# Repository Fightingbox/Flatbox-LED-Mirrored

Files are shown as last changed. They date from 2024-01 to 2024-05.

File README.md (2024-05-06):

# Flatbox-LED-Mirrored
Based on the [GP2040-CE](https://github.com/OpenStickCommunity/GP2040-CE) Flatbox Rev4

Add the colorful LEDs and the OLED display, perfect hardware change beased on the [Flatbox](https://github.com/jfedor2/flatbox) design by [jfedor2](https://github.com/jfedor2) powered by an RP2040 MCU.

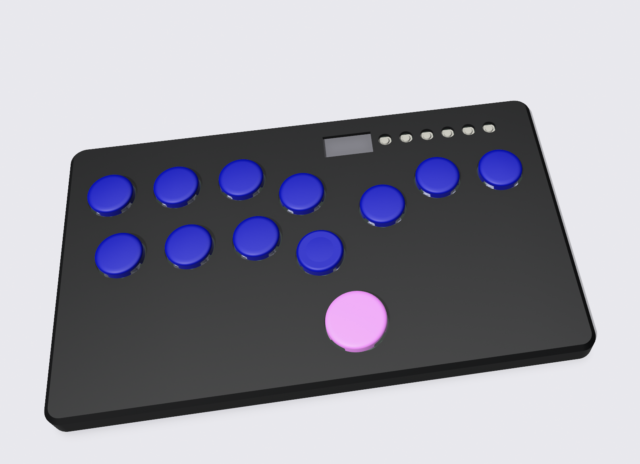
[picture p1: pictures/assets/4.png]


Flatbox-LED

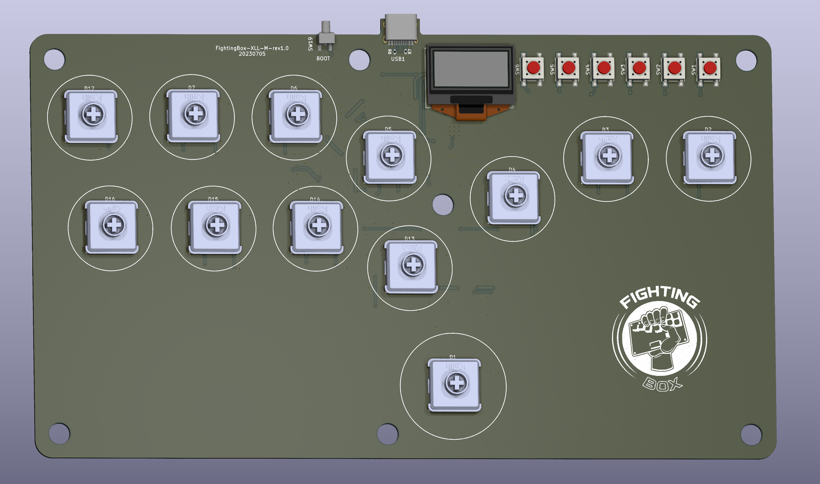
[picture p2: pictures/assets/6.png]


## Upgrade the firmware:
- Unplug your device.
- Put your device into Bootsel/USB mode. A new removable drive named RPI-RP2 should appear in your file explorer.
- Drag and drop the GP2040-CE_XXX.uf2 firmware into the removable drive.
- Wait for the device to automatically disconnect.

### If you encounter problems updating firmware, please refer to the official firmware update [Tutorial](https://gp2040-ce.info/?spm=a2g0o.detail.1000023.2.163cu936u936KZ#/installation).

## GP2040-CE Links

[Downloads](https://gp2040-ce.info/#/download) | [Installation](https://gp2040-ce.info/#/installation) | [Wiring](https://gp2040-ce.info/#/wiring) | [Usage](https://gp2040-ce.info/#/usage) | [FAQ](https://gp2040-ce.info/#/faq) | [GitHub](https://github.com/OpenStickCommunity/GP2040-CE)

Full documentation can be found at <https://gp2040-ce.info>

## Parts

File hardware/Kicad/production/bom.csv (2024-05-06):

Designator | Footprint | Quantity | Value | LCSC Part #
C1, C10, C4, C8 | 0402 | 4 | 1u | C52923
C11, C12, C13, C14, C15, C16, C5, C6, C7, C9 | 0402 | 10 | 100n | C1525
C17, C19 | 0402 | 2 | 1uF
C18 | 0603 | 1 | 4.7uF
C2, C3 | 0402 | 2 | 5p | C1570
C20 | 0603 | 1 | 2.2uF
D1, D12, D13, D14, D15, D16, D2, D3, D4, D5, D6, D7 | Kailh_socket_PG1353_LED_1U-4.8MM | 12 | KB_HOTSWAP_WS2812B
DS1 | TE_CON-0_1x30-1MP_P0.5mm_Horizontal-OLED-FPC | 1 | OLED-128O064D
H1, H2, H3, H4, H5, H6, H7 | MountingHole_6mm | 7 | MountingHole
R1, R5 | 0402 | 2 | 1k | C11702
R15 | 0402 | 1 | 390K
R16, R17 | 0402 | 2 | 4.7K
R2 | 0402 | 1 | 10k | C25744
R3, R4 | 0402 | 2 | 27 | C138021
R6, R7 | 0402 | 2 | 5.1k | C25905
SW1, SW2, SW3, SW4, SW5, SW6 | SW_Push_1P1T_NO_6x6mm_H5mm | 6 | SW_Push
SW19 | SW-K2-1109SE | 1 | SW_Push | C271750
U1 | SOT-23-5 | 1 | TLV73333PDBV | C134139
U2 | SOIC-8_5.23x5.23mm_P1.27mm | 1 | W25Q128JVS | C97521
U3 | RP2040-QFN-56 | 1 | RP2040 | C2040
USB1 | HRO-TYPE-C-31-M-12-Assembly | 1 | HRO-TYPE-C-31-M-12 | C165948
Y1 | Crystal_SMD_3225-4Pin_3.2x2.5mm | 1 | Crystal_GND24 | C9002

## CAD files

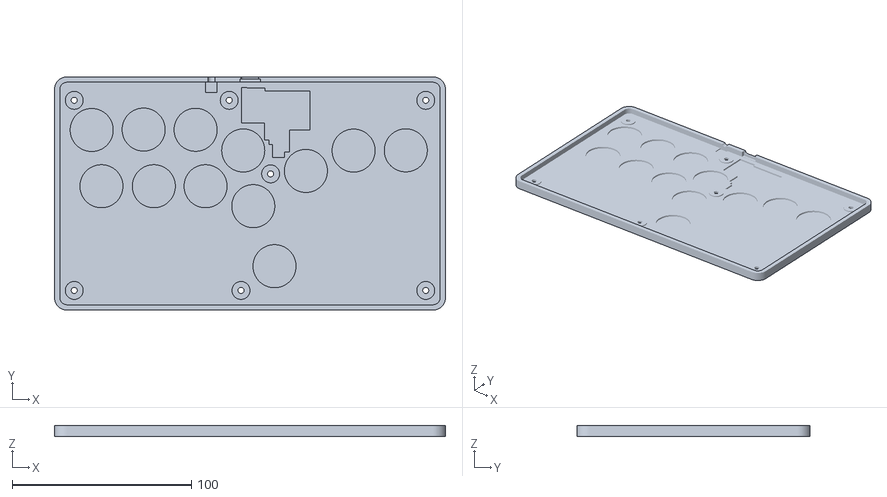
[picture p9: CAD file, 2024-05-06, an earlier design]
case/FightingBox-XLL-Mirror-Bottom-0711.stl
218.0 x 130.1 x 6.00

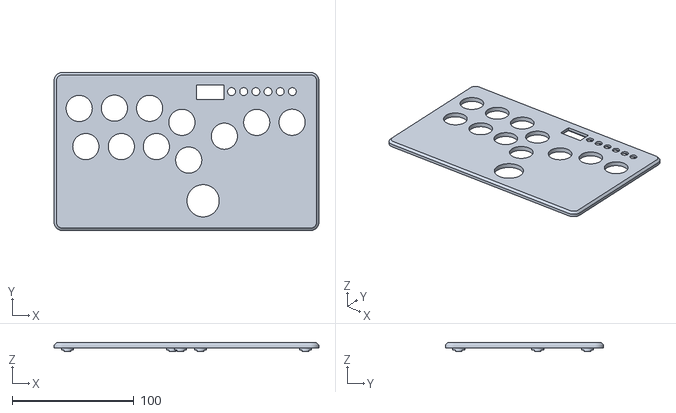
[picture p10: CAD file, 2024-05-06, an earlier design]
case/FightingBox-XLL-Mirror-TOP-0706.stl
218.0 x 130.1 x 7.20

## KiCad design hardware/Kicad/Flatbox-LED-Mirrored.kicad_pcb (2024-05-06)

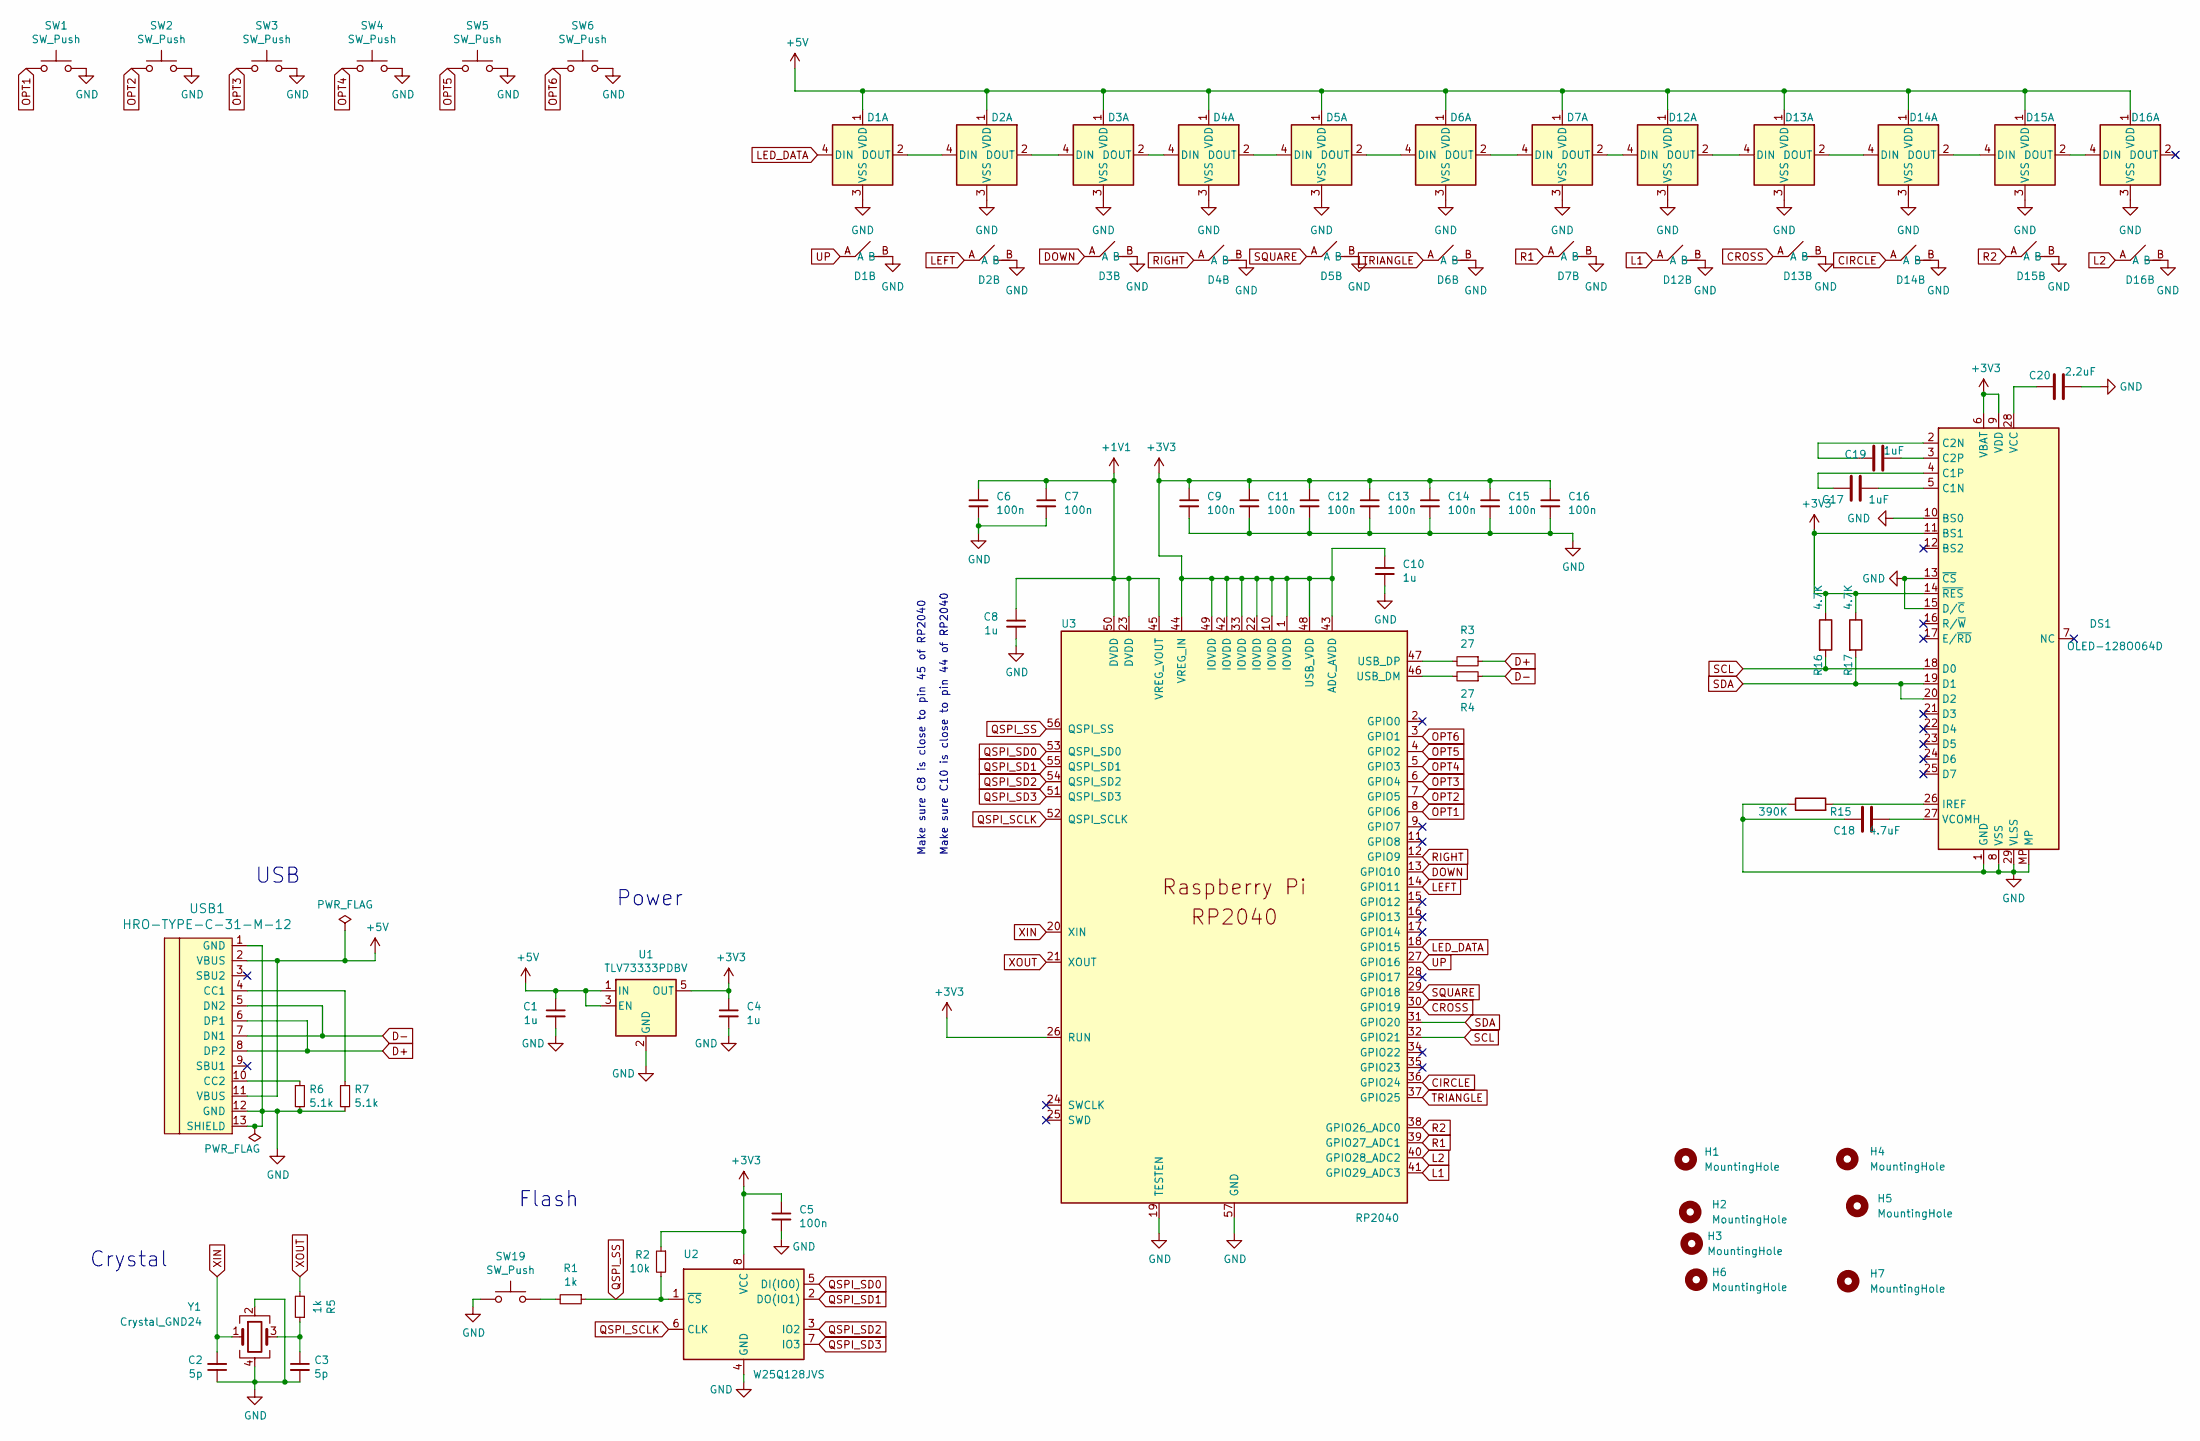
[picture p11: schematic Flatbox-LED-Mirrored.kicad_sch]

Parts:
C1, C4, C8, C10: 1u; C_0402_1005Metric; LCSC C52923
C2, C3: 5p; C_0402_1005Metric; LCSC C1570
C5, C6, C7, C9, C11, C12, C13, C14, C15, C16: 100n; C_0402_1005Metric; LCSC C1525
C17, C19: 1uF; C_0402_1005Metric
C18: 4.7uF; C_0603_1608Metric
C20: 2.2uF; C_0603_1608Metric
D1, D2, D3, D4, D5, D6, D7, D12, D13, D14, D15, D16: KB_HOTSWAP_WS2812B; Kailh_socket_PG1353_LED_1U
DS1: OLED-128O064D; TE_CON-0_1x30-1MP_P0.5mm_Horizontal-OLED-FPC
H1, H2, H3, H4, H5, H6, H7: MountingHole; MountingHole_6mm
R1, R5: 1k; R_0402_1005Metric; LCSC C11702
R2: 10k; R_0402_1005Metric; LCSC C25744
R3, R4: 27; R_0402_1005Metric; LCSC C138021
R6, R7: 5.1k; R_0402_1005Metric; LCSC C25905
R15: 390K; R_0402_1005Metric
R16, R17: 4.7K; R_0402_1005Metric
SW1, SW2, SW3, SW4, SW5, SW6: SW_Push; SW_Push_1P1T_NO_6x6mm_H5mm
SW19: SW_Push; SW-K2-1109SE; LCSC C271750
U1: TLV73333PDBV; SOT-23-5; LCSC C134139
U2: W25Q128JVS; SOIC-8_5.23x5.23mm_P1.27mm; LCSC C97521
U3: RP2040; RP2040-QFN-56; LCSC C2040
USB1: HRO-TYPE-C-31-M-12; HRO-TYPE-C-31-M-12-Assembly; LCSC C165948
Y1: Crystal_GND24; Crystal_SMD_3225-4Pin_3.2x2.5mm; LCSC C9002

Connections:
+1V1: C6.1, C7.1, C8.1, U3.23 (DVDD), U3.45 (VREG_VOUT), U3.50 (DVDD)
+3V3: C4.1, C5.1, C9.1, C10.1, C11.1, C12.1, C13.1, C14.1, C15.1, C16.1, DS1.6 (VBAT), DS1.9 (VDD), DS1.11 (BS1), DS1.14 (~RES), R2.1, R16.1, R17.1, U1.5 (OUT), U2.8 (VCC), U3.1 (IOVDD), U3.10 (IOVDD), U3.22 (IOVDD), U3.26 (RUN), U3.33 (IOVDD), U3.42 (IOVDD), U3.43 (ADC_AVDD), U3.44 (VREG_IN), U3.48 (USB_VDD), U3.49 (IOVDD)
+5V: C1.1, D1.1 (VDD), D2.1 (VDD), D3.1 (VDD), D4.1 (VDD), D5.1 (VDD), D6.1 (VDD), D7.1 (VDD), D12.1 (VDD), D13.1 (VDD), D14.1 (VDD), D15.1 (VDD), D16.1 (VDD), U1.1 (IN), U1.3 (EN), USB1.2 (VBUS), USB1.11 (VBUS)
CIRCLE: D14.A, U3.36 (GPIO24)
CROSS: D13.A, U3.30 (GPIO19)
D+: R3.1, USB1.6 (DP1), USB1.8 (DP2)
D-: R4.1, USB1.5 (DN2), USB1.7 (DN1)
DOWN: D3.A, U3.13 (GPIO10)
GND: C1.2, C2.1, C3.2, C4.2, C5.2, C6.2, C7.2, C8.2, C9.2, C10.2, C11.2, C12.2, C13.2, C14.2, C15.2, C16.2, C18.1, C20.2, D1.3 (VSS), D1.B, D2.3 (VSS), D2.B, D3.3 (VSS), D3.B, D4.3 (VSS), D4.B, D5.3 (VSS), D5.B, D6.3 (VSS), D6.B, D7.3 (VSS), D7.B, D12.3 (VSS), D12.B, D13.3 (VSS), D13.B, D14.3 (VSS), D14.B, D15.3 (VSS), D15.B, D16.3 (VSS), D16.B, DS1.1 (GND), DS1.8 (VSS), DS1.10 (BS0), DS1.13 (~CS), DS1.15 (D/~C), DS1.29 (VLSS), DS1.30 (GND), DS1.MP, R6.2, R7.2, R15.1, SW1.2, SW2.2, SW3.2, SW4.2, SW5.2, SW6.2, SW19.1, SW19.GND, U1.2 (GND), U2.4 (GND), U3.19 (TESTEN), U3.57 (GND), USB1.1 (GND), USB1.12 (GND), USB1.13 (SHIELD), Y1.2, Y1.4
L1: D12.A, U3.41 (GPIO29_ADC3)
L2: D16.A, U3.40 (GPIO28_ADC2)
LED_DATA: D1.4 (DIN), U3.18 (GPIO15)
unnamed: C3.1, R5.1, Y1.3
unnamed: D1.2 (DOUT), D2.4 (DIN)
unnamed: D2.2 (DOUT), D3.4 (DIN)
unnamed: D3.2 (DOUT), D4.4 (DIN)
unnamed: D4.2 (DOUT), D5.4 (DIN)
unnamed: D5.2 (DOUT), D6.4 (DIN)
unnamed: D6.2 (DOUT), D7.4 (DIN)
unnamed: D7.2 (DOUT), D12.4 (DIN)
unnamed: D12.2 (DOUT), D13.4 (DIN)
unnamed: D13.2 (DOUT), D14.4 (DIN)
unnamed: D14.2 (DOUT), D15.4 (DIN)
unnamed: D15.2 (DOUT), D16.4 (DIN)
unnamed: C17.2, DS1.5 (C1N)
unnamed: C17.1, DS1.4 (C1P)
unnamed: C19.1, DS1.2 (C2N)
unnamed: C19.2, DS1.3 (C2P)
unnamed: DS1.26 (IREF), R15.2
unnamed: C20.1, DS1.28 (VCC)
unnamed: C18.2, DS1.27 (VCOMH)
unnamed: R1.2, SW19.2
unnamed: R4.2, U3.46 (USB_DM)
unnamed: R3.2, U3.47 (USB_DP)
unnamed: R7.1, USB1.4 (CC1)
unnamed: R6.1, USB1.10 (CC2)
OPT1: SW1.1, U3.8 (GPIO6)
OPT2: SW2.1, U3.7 (GPIO5)
OPT3: SW3.1, U3.6 (GPIO4)
OPT4: SW4.1, U3.5 (GPIO3)
OPT5: SW5.1, U3.4 (GPIO2)
OPT6: SW6.1, U3.3 (GPIO1)
QSPI_SCLK: U2.6 (CLK), U3.52 (QSPI_SCLK)
QSPI_SD0: U2.5 (DI(IO0)), U3.53 (QSPI_SD0)
QSPI_SD1: U2.2 (DO(IO1)), U3.55 (QSPI_SD1)
QSPI_SD2: U2.3 (IO2), U3.54 (QSPI_SD2)
QSPI_SD3: U2.7 (IO3), U3.51 (QSPI_SD3)
QSPI_SS: R1.1, R2.2, U2.1 (~CS), U3.56 (QSPI_SS)
R1: D7.A, U3.39 (GPIO27_ADC1)
R2: D15.A, U3.38 (GPIO26_ADC0)
SCL: DS1.18 (D0), R16.2, U3.32 (GPIO21)
SDA: DS1.19 (D1), DS1.20 (D2), R17.2, U3.31 (GPIO20)
SQUARE: D5.A, U3.29 (GPIO18)
TRIANGLE: D6.A, U3.37 (GPIO25)
UP: D1.A, U3.27 (GPIO16)
XIN: C2.2, U3.20 (XIN), Y1.1
XOUT: R5.2, U3.21 (XOUT)

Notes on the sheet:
Make sure C10 is close to pin 44 of RP2040
Crystal
Flash
Make sure C8 is close to pin 45 of RP2040
USB
Power

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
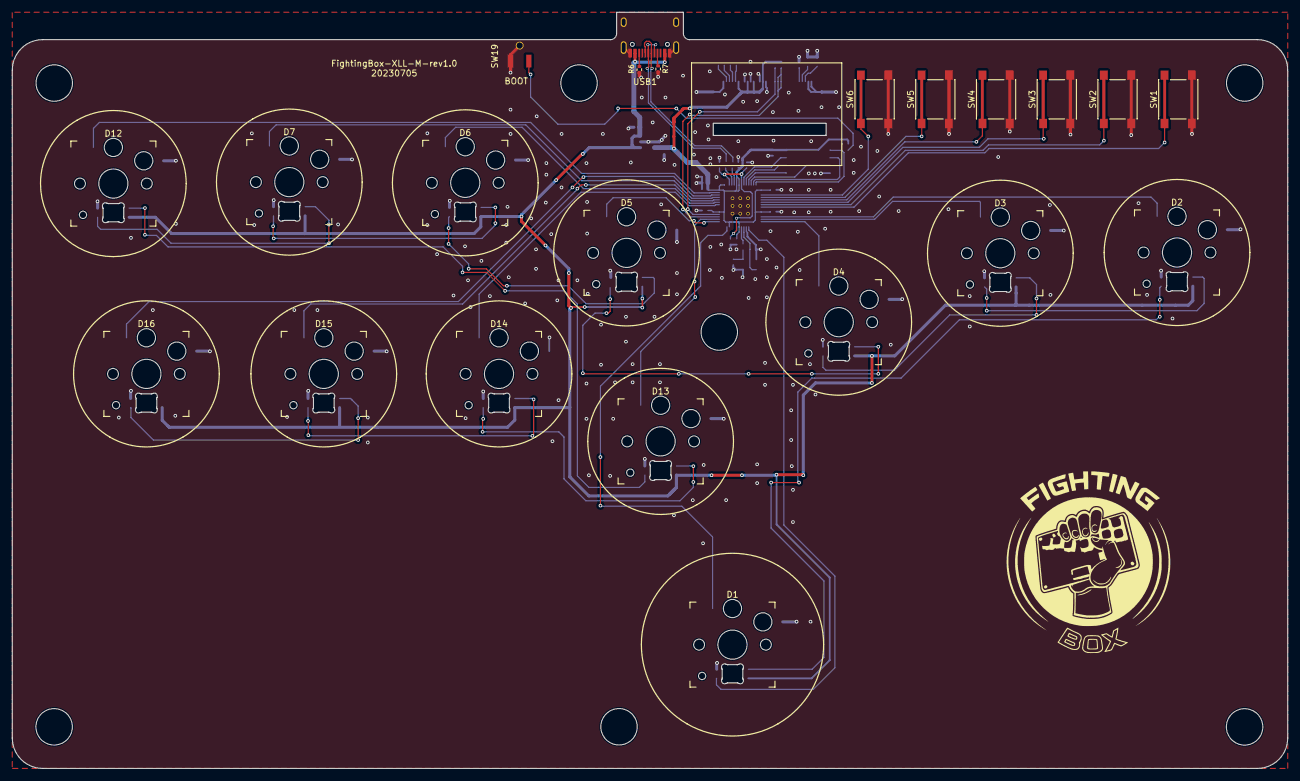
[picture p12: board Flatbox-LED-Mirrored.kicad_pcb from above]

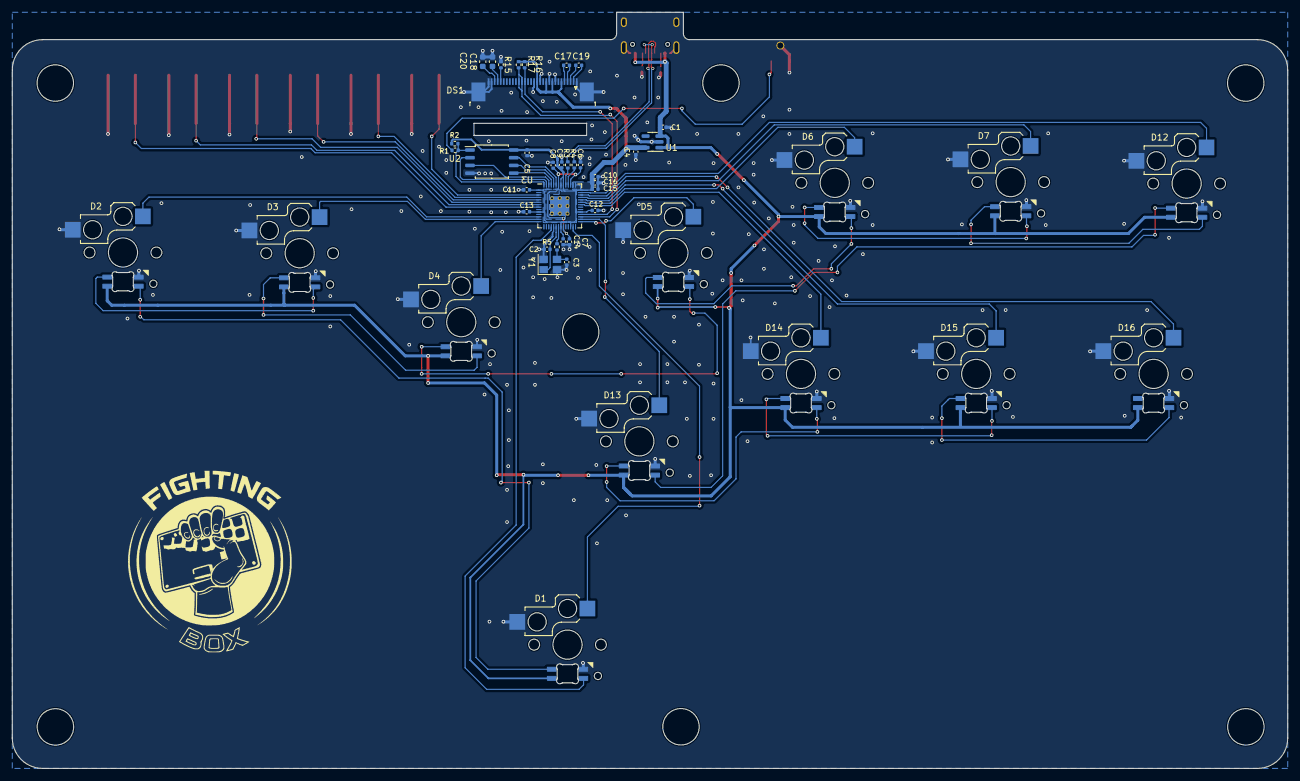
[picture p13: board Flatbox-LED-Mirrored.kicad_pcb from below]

Board: 2 copper layers, 210.0 x 124.5 mm, 62 parts (40 on the bottom side), 59 nets.

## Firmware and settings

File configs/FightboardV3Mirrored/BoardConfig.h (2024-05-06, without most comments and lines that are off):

#define FLATBOX_LED_CONFIG_H_
#include "enums.pb.h"
#include "class/hid/hid.h"
#define BOARD_CONFIG_LABEL "Flatbox LED Mirrored"
#define GPIO_PIN_16 GpioAction::BUTTON_PRESS_UP     // UP     | UP     | UP      | UP       | UP     | UP     |
#define GPIO_PIN_10 GpioAction::BUTTON_PRESS_DOWN   // DOWN   | DOWN   | DOWN    | DOWN     | DOWN   | DOWN   |
#define GPIO_PIN_09 GpioAction::BUTTON_PRESS_RIGHT  // RIGHT  | RIGHT  | RIGHT   | RIGHT    | RIGHT  | RIGHT  |
#define GPIO_PIN_11 GpioAction::BUTTON_PRESS_LEFT   // LEFT   | LEFT   | LEFT    | LEFT     | LEFT   | LEFT   |
#define GPIO_PIN_19 GpioAction::BUTTON_PRESS_B1     // B1     | A      | B       | Cross    | 2      | K1     |
#define GPIO_PIN_24 GpioAction::BUTTON_PRESS_B2     // B2     | B      | A       | Circle   | 3      | K2     |
#define GPIO_PIN_26 GpioAction::BUTTON_PRESS_R2     // R2     | RT     | ZR      | R2       | 8      | K3     |
#define GPIO_PIN_28 GpioAction::BUTTON_PRESS_L2     // L2     | LT     | ZL      | L2       | 7      | K4     |
#define GPIO_PIN_18 GpioAction::BUTTON_PRESS_B3     // B3     | X      | Y       | Square   | 1      | P1     |
#define GPIO_PIN_25 GpioAction::BUTTON_PRESS_B4     // B4     | Y      | X       | Triangle | 4      | P2     |
#define GPIO_PIN_27 GpioAction::BUTTON_PRESS_R1     // R1     | RB     | R       | R1       | 6      | P3     |
#define GPIO_PIN_29 GpioAction::BUTTON_PRESS_L1     // L1     | LB     | L       | L1       | 5      | P4     |
#define GPIO_PIN_05 GpioAction::BUTTON_PRESS_S1     // S1     | Back   | Minus   | Select   | 9      | Coin   |
#define GPIO_PIN_06 GpioAction::BUTTON_PRESS_S2     // S2     | Start  | Plus    | Start    | 10     | Start  |
#define GPIO_PIN_02 GpioAction::BUTTON_PRESS_L3     // L3     | LS     | LS      | L3       | 11     | LS     |
#define GPIO_PIN_01 GpioAction::BUTTON_PRESS_R3     // R3     | RS     | RS      | R3       | 12     | RS     |
#define GPIO_PIN_04 GpioAction::BUTTON_PRESS_A1     // A1     | Guide  | Home    | PS       | 13     | ~      |
#define GPIO_PIN_03 GpioAction::BUTTON_PRESS_A2     // A2     | ~      | Capture | ~        | 14     | ~      |
#define KEY_DPAD_UP     HID_KEY_ARROW_UP      // UP     | UP     | UP      | UP       | UP     | UP     |
#define KEY_DPAD_DOWN   HID_KEY_ARROW_DOWN    // DOWN   | DOWN   | DOWN    | DOWN     | DOWN   | DOWN   |
#define KEY_DPAD_RIGHT  HID_KEY_ARROW_RIGHT   // RIGHT  | RIGHT  | RIGHT   | RIGHT    | RIGHT  | RIGHT  |
#define KEY_DPAD_LEFT   HID_KEY_ARROW_LEFT    // LEFT   | LEFT   | LEFT    | LEFT     | LEFT   | LEFT   |
#define KEY_BUTTON_B1   HID_KEY_SHIFT_LEFT    // B1     | A      | B       | Cross    | 2      | K1     |
#define KEY_BUTTON_B2   HID_KEY_Z             // B2     | B      | A       | Circle   | 3      | K2     |
#define KEY_BUTTON_R2   HID_KEY_X             // R2     | RT     | ZR      | R2       | 8      | K3     |
#define KEY_BUTTON_L2   HID_KEY_V             // L2     | LT     | ZL      | L2       | 7      | K4     |
#define KEY_BUTTON_B3   HID_KEY_CONTROL_LEFT  // B3     | X      | Y       | Square   | 1      | P1     |
#define KEY_BUTTON_B4   HID_KEY_ALT_LEFT      // B4     | Y      | X       | Triangle | 4      | P2     |
#define KEY_BUTTON_R1   HID_KEY_SPACE         // R1     | RB     | R       | R1       | 6      | P3     |
#define KEY_BUTTON_L1   HID_KEY_C             // L1     | LB     | L       | L1       | 5      | P4     |
#define KEY_BUTTON_S1   HID_KEY_5             // S1     | Back   | Minus   | Select   | 9      | Coin   |
#define KEY_BUTTON_S2   HID_KEY_1             // S2     | Start  | Plus    | Start    | 10     | Start  |
#define KEY_BUTTON_L3   HID_KEY_EQUAL         // L3     | LS     | LS      | L3       | 11     | LS     |
#define KEY_BUTTON_R3   HID_KEY_MINUS         // R3     | RS     | RS      | R3       | 12     | RS     |
#define KEY_BUTTON_A1   HID_KEY_9             // A1     | Guide  | Home    | PS       | 13     | ~      |
#define KEY_BUTTON_A2   HID_KEY_F2            // A2     | ~      | Capture | ~        | 14     | ~      |
#define KEY_BUTTON_FN   -1                    // Hotkey Function                                        |
#define DEFAULT_INPUT_MODE_R1 INPUT_MODE_XBONE
#define DEFAULT_INPUT_MODE_B4 INPUT_MODE_PS5
#define DEFAULT_PS5AUTHENTICATION_TYPE INPUT_MODE_AUTH_TYPE_USB
#define BOARD_LEDS_PIN 15
#define LED_BRIGHTNESS_MAXIMUM 100
#define LED_BRIGHTNESS_STEPS 5
#define LED_FORMAT LED_FORMAT_GRB
#define LEDS_PER_PIXEL 1
#define LEDS_BASE_ANIMATION_INDEX 1
#define HAS_I2C_DISPLAY 1
#define I2C0_ENABLED 1
#define I2C0_PIN_SDA 20
#define I2C0_PIN_SCL 21
#define BUTTON_LAYOUT BUTTON_LAYOUT_STICKLESS
#define BUTTON_LAYOUT_RIGHT BUTTON_LAYOUT_STICKLESSB
#define SPLASH_MODE SPLASH_MODE_STATIC
#define SPLASH_DURATION 2500
#define LEDS_DPAD_LEFT   1
#define LEDS_DPAD_DOWN   2
#define LEDS_DPAD_RIGHT  3
#define LEDS_DPAD_UP     0
#define LEDS_BUTTON_B3   4
#define LEDS_BUTTON_B4   5
#define LEDS_BUTTON_R1   6
#define LEDS_BUTTON_L1   7
#define LEDS_BUTTON_B1   8
#define LEDS_BUTTON_B2   9
#define LEDS_BUTTON_R2   10
#define LEDS_BUTTON_L2   11
#define LEDS_BUTTON_S1   -1
#define LEDS_BUTTON_S2   -1
#define LEDS_BUTTON_L3   -1
#define LEDS_BUTTON_R3   -1
#define LEDS_BUTTON_A1   -1
#define LEDS_BUTTON_A2   -1
#define DEFAULT_SPLASH \
0x00,0x00,0x00,0x00,0x00,0x00,0x00,0x00,0x00,0x00,0x00,0x00,0x00,0x00,0x00,0x00, \
0x00,0x00,0x00,0x00,0x00,0x00,0x00,0x00,0x00,0x00,0x00,0x00,0x00,0x00,0x00,0x00, \
0x00,0x00,0x00,0x00,0x00,0x00,0x00,0x00,0x00,0x00,0x00,0x00,0x00,0x00,0x00,0x00, \
0x00,0x00,0x00,0x00,0x00,0x00,0x00,0x00,0x00,0x00,0x00,0x00,0x00,0x00,0x00,0x00, \
0x00,0x00,0x00,0x00,0x00,0x00,0x00,0x00,0x00,0x00,0x00,0x00,0x00,0x00,0x00,0x00, \
0x00,0x00,0x00,0x00,0x00,0x00,0x00,0x00,0x00,0x00,0x00,0x00,0x00,0x00,0x00,0x00, \
0x00,0x00,0x00,0x00,0x00,0x07,0xFF,0xE0,0x07,0xFF,0xE0,0x00,0x00,0x00,0x00,0x00, \
0x00,0x00,0x00,0x00,0x00,0x1F,0xFF,0xE0,0x07,0xFF,0xF8,0x00,0x00,0x00,0x00,0x00, \
0x00,0x00,0x00,0x00,0x00,0x3F,0xFF,0xE0,0x07,0xFF,0xFC,0x00,0x00,0x00,0x00,0x00, \
0x00,0x00,0x00,0x00,0x00,0x3F,0xFF,0xE7,0xE7,0xFF,0xFC,0x00,0x00,0x00,0x00,0x00, \
0x00,0x00,0x00,0x00,0x00,0x7F,0xFF,0xE7,0xE7,0xFF,0xFE,0x00,0x00,0x00,0x00,0x00, \
0x00,0x00,0x00,0x00,0x00,0x7F,0x00,0x07,0xE0,0x00,0xFE,0x00,0x00,0x00,0x00,0x00, \
0x00,0x00,0x00,0x00,0x00,0x7E,0x00,0x07,0xE0,0x00,0x7E,0x00,0x00,0x00,0x00,0x00, \
0x00,0x00,0x00,0x00,0x00,0x7C,0x7F,0x07,0xE0,0xFE,0x3E,0x00,0x00,0x00,0x00,0x00, \
0x00,0x00,0x00,0x00,0x00,0x7C,0x7F,0x87,0xE0,0xFF,0x3E,0x00,0x00,0x00,0x00,0x00, \
0x00,0x00,0x00,0x00,0x00,0x7C,0xFF,0x87,0xE1,0xFF,0x3E,0x00,0x00,0x00,0x00,0x00, \
0x00,0x00,0x00,0x00,0x00,0x7C,0xFF,0x87,0xE1,0xFF,0x3E,0x00,0x00,0x00,0x00,0x00, \
0x00,0x00,0x00,0x00,0x00,0x7C,0xFF,0x87,0xE1,0xFF,0x3E,0x00,0x00,0x00,0x00,0x00, \
0x00,0x00,0x00,0x00,0x00,0x7C,0xFF,0x87,0xE1,0xFF,0x3E,0x00,0x00,0x00,0x00,0x00, \
0x00,0x00,0x00,0x00,0x00,0x7C,0xFF,0x87,0xE1,0xFF,0x3E,0x00,0x00,0x00,0x00,0x00, \
0x00,0x00,0x00,0x00,0x00,0x7C,0xFF,0x87,0xE1,0xFF,0x3E,0x00,0x00,0x00,0x00,0x00, \
0x00,0x00,0x00,0x00,0x00,0x7C,0xFF,0x87,0xE1,0xFF,0x3E,0x00,0x00,0x00,0x00,0x00, \
0x00,0x00,0x00,0x00,0x00,0x7C,0xFF,0x87,0xE1,0xFF,0x3E,0x00,0x00,0x00,0x00,0x00, \
0x00,0x00,0x00,0x00,0x00,0x7C,0xFF,0x87,0xE1,0xFF,0x3E,0x00,0x00,0x00,0x00,0x00, \
0x00,0x00,0x00,0x00,0x00,0x7C,0xFF,0x87,0xE1,0xFF,0x3E,0x00,0x00,0x00,0x00,0x00, \
0x00,0x00,0x00,0x00,0x00,0x7C,0xFF,0x87,0xE1,0xFF,0x3E,0x00,0x00,0x00,0x00,0x00, \
0x00,0x00,0x00,0x00,0x00,0x7C,0xFF,0x87,0xE1,0xFF,0x3E,0x00,0x00,0x00,0x00,0x00, \
0x00,0x00,0x00,0x00,0x00,0x7C,0xFF,0x87,0xE1,0xFF,0x3E,0x00,0x00,0x00,0x00,0x00, \
0x00,0x00,0x00,0x00,0x00,0x7C,0x7F,0x07,0xE0,0xFF,0x3E,0x00,0x00,0x00,0x00,0x00, \
0x00,0x00,0x00,0x00,0x00,0x7E,0x3E,0x07,0xE0,0x7C,0x7E,0x00,0x00,0x00,0x00,0x00, \
0x00,0x00,0x00,0x00,0x00,0x7E,0x00,0x07,0xE0,0x00,0x7E,0x00,0x00,0x00,0x00,0x00, \
0x00,0x00,0x00,0x00,0x00,0x7F,0x00,0x07,0xE0,0x00,0xFE,0x00,0x00,0x00,0x00,0x00, \
0x00,0x00,0x00,0x00,0x00,0x7F,0xFF,0xE7,0xE7,0xFF,0xFE,0x00,0x00,0x00,0x00,0x00, \
0x00,0x00,0x00,0x00,0x00,0x3F,0xFF,0xE7,0xE7,0xFF,0xFC,0x00,0x00,0x00,0x00,0x00, \
0x00,0x00,0x00,0x00,0x00,0x1F,0xFF,0xE0,0x07,0xFF,0xF8,0x00,0x00,0x00,0x00,0x00, \
0x00,0x00,0x00,0x00,0x00,0x0F,0xFF,0xE0,0x07,0xFF,0xF0,0x00,0x00,0x00,0x00,0x00, \
0x00,0x00,0x00,0x00,0x00,0x07,0xFF,0xE0,0x07,0xFF,0xE0,0x00,0x00,0x00,0x00,0x00, \
0x00,0x00,0x00,0x00,0x00,0x00,0x00,0x00,0x00,0x00,0x00,0x00,0x00,0x00,0x00,0x00, \
0x00,0x00,0x00,0x00,0x00,0x00,0x00,0x00,0x00,0x00,0x00,0x00,0x00,0x00,0x00,0x00, \
0x00,0x00,0x00,0x00,0x00,0x00,0x00,0x00,0x00,0x00,0x00,0x00,0x00,0x00,0x00,0x00, \
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

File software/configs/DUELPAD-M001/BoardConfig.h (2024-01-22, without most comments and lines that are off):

#define DUELPAD_M001_CONFIG_H_
#include "enums.pb.h"
#define BOARD_CONFIG_LABEL "DUELPAD_M001"
#define GPIO_PIN_16 GpioAction::BUTTON_PRESS_UP     // UP     | UP     | UP      | UP       | UP     | UP     |
#define GPIO_PIN_10 GpioAction::BUTTON_PRESS_DOWN   // DOWN   | DOWN   | DOWN    | DOWN     | DOWN   | DOWN   |
#define GPIO_PIN_11 GpioAction::BUTTON_PRESS_RIGHT  // RIGHT  | RIGHT  | RIGHT   | RIGHT    | RIGHT  | RIGHT  |
#define GPIO_PIN_09 GpioAction::BUTTON_PRESS_LEFT   // LEFT   | LEFT   | LEFT    | LEFT     | LEFT   | LEFT   |
#define GPIO_PIN_19 GpioAction::BUTTON_PRESS_B1     // B1     | A      | B       | Cross    | 2      | K1     |
#define GPIO_PIN_24 GpioAction::BUTTON_PRESS_B2     // B2     | B      | A       | Circle   | 3      | K2     |
#define GPIO_PIN_26 GpioAction::BUTTON_PRESS_R2     // R2     | RT     | ZR      | R2       | 8      | K3     |
#define GPIO_PIN_28 GpioAction::BUTTON_PRESS_L2     // L2     | LT     | ZL      | L2       | 7      | K4     |
#define GPIO_PIN_18 GpioAction::BUTTON_PRESS_B3     // B3     | X      | Y       | Square   | 1      | P1     |
#define GPIO_PIN_25 GpioAction::BUTTON_PRESS_B4     // B4     | Y      | X       | Triangle | 4      | P2     |
#define GPIO_PIN_27 GpioAction::BUTTON_PRESS_R1     // R1     | RB     | R       | R1       | 6      | P3     |
#define GPIO_PIN_29 GpioAction::BUTTON_PRESS_L1     // L1     | LB     | L       | L1       | 5      | P4     |
#define GPIO_PIN_05 GpioAction::BUTTON_PRESS_S1     // S1     | Back   | Minus   | Select   | 9      | Coin   |
#define GPIO_PIN_06 GpioAction::BUTTON_PRESS_S2     // S2     | Start  | Plus    | Start    | 10     | Start  |
#define GPIO_PIN_02 GpioAction::BUTTON_PRESS_L3     // L3     | LS     | LS      | L3       | 11     | LS     |
#define GPIO_PIN_01 GpioAction::BUTTON_PRESS_R3     // R3     | RS     | RS      | R3       | 12     | RS     |
#define GPIO_PIN_04 GpioAction::BUTTON_PRESS_A1     // A1     | Guide  | Home    | PS       | 13     | ~      |
#define GPIO_PIN_03 GpioAction::BUTTON_PRESS_A2     // A2     | ~      | Capture | ~        | 14     | ~      |
#define KEY_DPAD_UP     HID_KEY_ARROW_UP      // UP     | UP     | UP      | UP       | UP     | UP     |
#define KEY_DPAD_DOWN   HID_KEY_ARROW_DOWN    // DOWN   | DOWN   | DOWN    | DOWN     | DOWN   | DOWN   |
#define KEY_DPAD_RIGHT  HID_KEY_ARROW_RIGHT   // RIGHT  | RIGHT  | RIGHT   | RIGHT    | RIGHT  | RIGHT  |
#define KEY_DPAD_LEFT   HID_KEY_ARROW_LEFT    // LEFT   | LEFT   | LEFT    | LEFT     | LEFT   | LEFT   |
#define KEY_BUTTON_B1   HID_KEY_SHIFT_LEFT    // B1     | A      | B       | Cross    | 2      | K1     |
#define KEY_BUTTON_B2   HID_KEY_Z             // B2     | B      | A       | Circle   | 3      | K2     |
#define KEY_BUTTON_R2   HID_KEY_X             // R2     | RT     | ZR      | R2       | 8      | K3     |
#define KEY_BUTTON_L2   HID_KEY_V             // L2     | LT     | ZL      | L2       | 7      | K4     |
#define KEY_BUTTON_B3   HID_KEY_CONTROL_LEFT  // B3     | X      | Y       | Square   | 1      | P1     |
#define KEY_BUTTON_B4   HID_KEY_ALT_LEFT      // B4     | Y      | X       | Triangle | 4      | P2     |
#define KEY_BUTTON_R1   HID_KEY_SPACE         // R1     | RB     | R       | R1       | 6      | P3     |
#define KEY_BUTTON_L1   HID_KEY_C             // L1     | LB     | L       | L1       | 5      | P4     |
#define KEY_BUTTON_S1   HID_KEY_5             // S1     | Back   | Minus   | Select   | 9      | Coin   |
#define KEY_BUTTON_S2   HID_KEY_1             // S2     | Start  | Plus    | Start    | 10     | Start  |
#define KEY_BUTTON_L3   HID_KEY_EQUAL         // L3     | LS     | LS      | L3       | 11     | LS     |
#define KEY_BUTTON_R3   HID_KEY_MINUS         // R3     | RS     | RS      | R3       | 12     | RS     |
#define KEY_BUTTON_A1   HID_KEY_9             // A1     | Guide  | Home    | PS       | 13     | ~      |
#define KEY_BUTTON_A2   HID_KEY_F2            // A2     | ~      | Capture | ~        | 14     | ~      |
#define KEY_BUTTON_FN   -1                    // Hotkey Function                                        |
#define PIN_BUTTON_FN        -1                      // Hotkey Function
#define PIN_BUTTON_REVERSE   -1                   // UDLR Reverse
#define PIN_BUTTON_TURBO     -1                     // Turbo
#define JSLIDER_ENABLED 1
#define PIN_SLIDER_ONE        13                // Left Stick Slider
#define PIN_SLIDER_TWO        12                // Right Stick Slider
#define SLIDER_SOCD_ENABLED 1
#define PIN_SLIDER_SOCD_ONE   14                // SOCD Slider Pin One
#define PIN_SLIDER_SOCD_TWO   17                // SOCD Slider Pin Two
#define DEFAULT_SOCD_MODE SOCD_MODE_NEUTRAL
#define SLIDER_SOCD_SLOT_ONE SOCD_MODE_UP_PRIORITY
#define SLIDER_SOCD_SLOT_TWO  SOCD_MODE_SECOND_INPUT_PRIORITY
#define SLIDER_SOCD_SLOT_DEFAULT SOCD_MODE_NEUTRAL
#define DEFAULT_FORCED_SETUP_MODE FORCED_SETUP_MODE_OFF // 	FORCED_SETUP_MODE_OFF, FORCED_SETUP_MODE_LOCK_MODE_SWITCH, FORCED_SETUP_MODE_LOCK_WEB_CONFIG, FORCED_SETUP_MODE_LOCK_BOTH
#define DEFAULT_LOCK_HOTKEYS false // or true
#define DEFAULT_PS4CONTROLLER_TYPE PS4_CONTROLLER
#define TURBO_LED_PIN -1
#define BOARD_LEDS_PIN 15
#define REVERSE_LED_PIN -1
#define LED_BRIGHTNESS_MAXIMUM 150
#define LED_BRIGHTNESS_STEPS 5
#define LED_FORMAT LED_FORMAT_GRB
#define LEDS_PER_PIXEL 1
#define LEDS_DPAD_LEFT   0 // 11
#define LEDS_DPAD_DOWN   1//10
#define LEDS_DPAD_RIGHT  2//9
#define LEDS_DPAD_UP     11
#define LEDS_BUTTON_B3   3
#define LEDS_BUTTON_B4   4
#define LEDS_BUTTON_R1   5
#define LEDS_BUTTON_L1   6
#define LEDS_BUTTON_B1   10
#define LEDS_BUTTON_B2   9
#define LEDS_BUTTON_R2   8
#define LEDS_BUTTON_L2   7
#define LEDS_BUTTON_S1   -1
#define LEDS_BUTTON_S2   -1
#define LEDS_BUTTON_L3   -1
#define LEDS_BUTTON_R3   -1
#define LEDS_BUTTON_A1   -1
#define LEDS_BUTTON_A2   -1
#define PLED_TYPE PLED_TYPE_NONE
#define PLED1_PIN -1
#define PLED2_PIN -1
#define PLED3_PIN -1
#define PLED4_PIN -1
#define ANALOG_ADC_1_VRX -1
#define ANALOG_ADC_1_VRY -1
#define ANALOG_ADC_1_MODE DPAD_MODE_LEFT_ANALOG
#define ANALOG_ADC_1_INVERT INVERT_NONE
#define ANALOG_ADC_2_VRX -1
#define ANALOG_ADC_2_VRY -1
#define ANALOG_ADC_2_MODE DPAD_MODE_RIGHT_ANALOG
#define ANALOG_ADC_2_INVERT INVERT_NONE
#define HAS_I2C_DISPLAY 1
#define I2C_SDA_PIN   20
#define I2C_SCL_PIN   21
#define SPLASH_MODE SPLASH_MODE_STATIC
#define SPLASH_DURATION 7500 // Duration in milliseconds
#define BUTTON_LAYOUT BUTTON_LAYOUT_STICKLESS
#define BUTTON_LAYOUT_RIGHT BUTTON_LAYOUT_STICKLESSB
#define REVERSE_UP_DEFAULT 1
#define REVERSE_DOWN_DEFAULT 1
#define REVERSE_LEFT_DEFAULT 1
#define REVERSE_RIGHT_DEFAULT 1
#define BOARD_LED_TYPE ON_BOARD_LED_MODE_OFF
#define PIN_DUAL_DIRECTIONAL_UP -1
#define PIN_DUAL_DIRECTIONAL_DOWN -1
#define PIN_DUAL_DIRECTIONAL_LEFT -1
#define PIN_DUAL_DIRECTIONAL_RIGHT -1
#define DUAL_DIRECTIONAL_STICK_MODE DPAD_MODE_DIGITAL
#define DUAL_DIRECTIONAL_COMBINE_MODE DUAL_COMBINE_MODE_MIXED
#define BOOTSEL_BUTTON_MASK 0 // 0 means none, get other mask from GamepadState.h
#define EXTRA_BUTTON_MASK 0 // 0 means none, get other mask from GamepadState.h
#define EXTRA_BUTTON_PIN -1
#define FOCUS_MODE_ENABLED 1
#define FOCUS_MODE_BUTTON_MASK GAMEPAD_MASK_S1 | GAMEPAD_MASK_S2 | GAMEPAD_MASK_A1 | GAMEPAD_MASK_A2 | GAMEPAD_MASK_L3 | GAMEPAD_MASK_R3 // 0 means none, get other mask from GamepadState.h
#define FOCUS_MODE_PIN 8
#define FOCUS_MODE_OLED_LOCK_ENABLED 1
#define FOCUS_MODE_RGB_LOCK_ENABLED 1
#define FOCUS_MODE_BUTTON_LOCK_ENABLED 1
#define PSPASSTHROUGH_ENABLED 1
#define PSPASSTHROUGH_PIN_DPLUS 22
#define KEY_DPAD_UP     HID_KEY_ARROW_UP      // UP
#define KEY_DPAD_DOWN   HID_KEY_ARROW_DOWN    // DOWN
#define KEY_DPAD_RIGHT  HID_KEY_ARROW_RIGHT   // RIGHT
#define KEY_DPAD_LEFT   HID_KEY_ARROW_LEFT    // LEFT
#define KEY_BUTTON_B1   HID_KEY_SHIFT_LEFT    // B1 / A / B / Cross / 2 / K1
#define KEY_BUTTON_B2   HID_KEY_Z             // B2 / B / A / Circle / 3 / K2
#define KEY_BUTTON_R2   HID_KEY_X             // R2 / RT / ZR / R2 / 8 / K3
#define KEY_BUTTON_L2   HID_KEY_V             // L2 / LT / ZL / L2 / 7 / K4
#define KEY_BUTTON_B3   HID_KEY_CONTROL_LEFT  // B3 / X / Y / Square / 1 / P1
#define KEY_BUTTON_B4   HID_KEY_ALT_LEFT      // B4 / Y / X / Triangle / 4 / P2
#define KEY_BUTTON_R1   HID_KEY_SPACE         // R1 / RB / R / R1 / 6 / P3
#define KEY_BUTTON_L1   HID_KEY_C             // L1 / LB / L / L1 / 5 / P4
#define KEY_BUTTON_S1   HID_KEY_5             // S1 / Back / Minus / Select / 9 / Coin
#define KEY_BUTTON_S2   HID_KEY_1             // S2 / Start / Plus / Start / 10 / Start
#define KEY_BUTTON_L3   HID_KEY_EQUAL         // L3 / LS / LS / L3 / 11 / LS
#define KEY_BUTTON_R3   HID_KEY_MINUS         // R3 / RS / RS / R3 / 12 / RS
#define KEY_BUTTON_A1   HID_KEY_9             // A1 / Guide / Home / PS / 13 / ~
#define KEY_BUTTON_A2   HID_KEY_F2            // A2 / ~ / Capture / ~ / 14 / ~
#define DEFAULT_SPLASH \
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

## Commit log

2024-01-19 update flatbox led to v0.7.7
2024-01-19 flatbox led update to v0.7.7
2024-01-22 add the oled splash for Flatbox-LED
2024-03-26 fix the Dpad left right keys
    [BoardConfig.h]
2024-03-26 open source the PCB and the 3D print Case
    [FightingBox-XLL-Mirror-Bottom-0711.stl, FightingBox-XLL-Mirror-TOP-0706.stl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]
2024-05-06 update to 0.7.8
    [FightingBox-XLL-Mirror-Bottom-0711.stl, FightingBox-XLL-Mirror-TOP-0706.stl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]

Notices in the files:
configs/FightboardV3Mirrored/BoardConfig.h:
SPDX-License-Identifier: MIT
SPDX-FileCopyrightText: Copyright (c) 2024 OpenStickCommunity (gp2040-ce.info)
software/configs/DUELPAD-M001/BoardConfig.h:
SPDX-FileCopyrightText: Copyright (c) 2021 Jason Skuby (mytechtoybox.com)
